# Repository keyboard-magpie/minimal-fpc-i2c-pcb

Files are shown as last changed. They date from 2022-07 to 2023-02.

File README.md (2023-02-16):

# minimal-fpc-i2c-pcb
Minimal adapter board for converting keyboard i2c oled pins to ffc/fpc ribbon cable for keyboards such as crkbd, kimiko or kyria, intended to make using cirque glidepoint trackpads easier with keyboards that already have an OLED header.
Screenshot_2022-07-07_at_13 14 48

# how to use
To use the TM035035 and TM040040 with 5v controllers, on the back trackpad, remove R1 for I2C, and remove R7 and R8 for 5V (leave these if using with 3v3 controllers i.e. rp2040.

# holders
In the holders folder you will find holders for the curved overlays (35 and 40mm- please note there was an earlier misnaming of these files which I have corrected as of 16 Feb 2023).

# production
Please note there is a small error in the cpl file for the ffc connector that comes from the footprint for it. JLC should correct its placement for you.

Connector used is this one from LCSC: https://lcsc.com/product-detail/FFC-FPC-Connectors_SHENZHEN-ATOM-TECH-FPC05012-09200_C479750.html

# alternative FPC connectors: 
https://www.digikey.co.uk/en/products/detail/hirose-electric-co-ltd/FH12-12S-0.5SH-55/1110374 \
https://www.digikey.co.uk/en/products/detail/gct/FFC2B35-12-G/15970866 \
Both of the above were suggested by u/idyllic on discord and look to have a footprint that is very close the the LCSC part above and should be compatible.

# ffc/fpc cables
Any generic flat flex cable can be used, they are 12 position, 0.5mm pitch, same-sided contacts. The molex extra flex and primo flex series from mouser seem to work well.

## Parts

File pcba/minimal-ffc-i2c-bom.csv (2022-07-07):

Comment | Designator | Footprint | LCSC Part #
4.7k Resistor | R1, R2 | Resistor_SMD:R_0805_2012Metric_Pad1.20x1.40mm_HandSolder | C441952
12 pin 0.5mm pitch FPC connector | J2 | minimal-ffc-i2c:FPC-SMD_FPC05012-09200-.5mm-rev | C479750

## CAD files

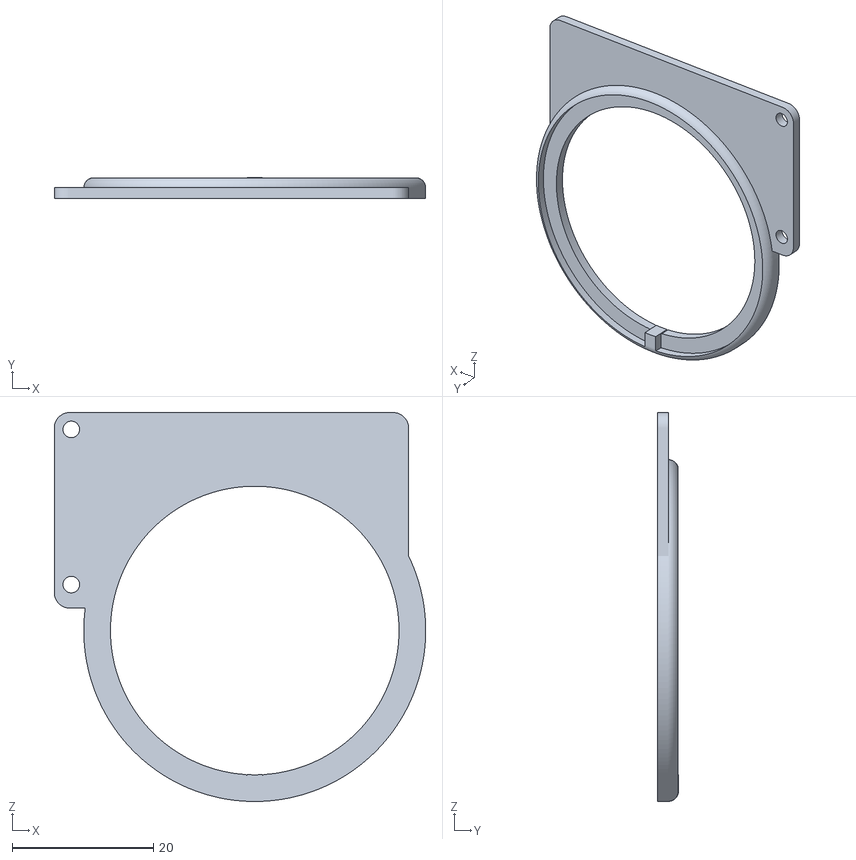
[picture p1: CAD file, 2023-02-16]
holders/lily-cirque40-curved-holder.stl
52.7 x 3.00 x 55.2

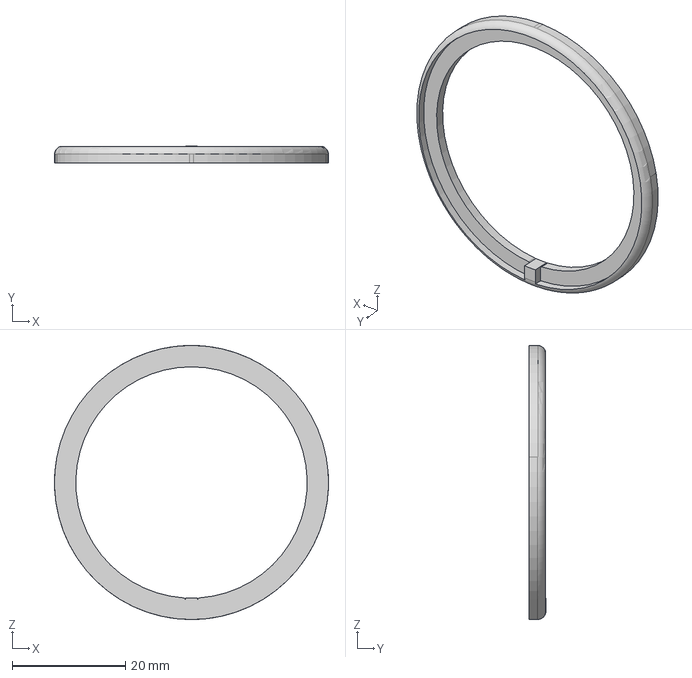
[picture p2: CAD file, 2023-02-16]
holders/cirque-40-curved-ring.step
48.5 x 3.00 x 48.5 mm

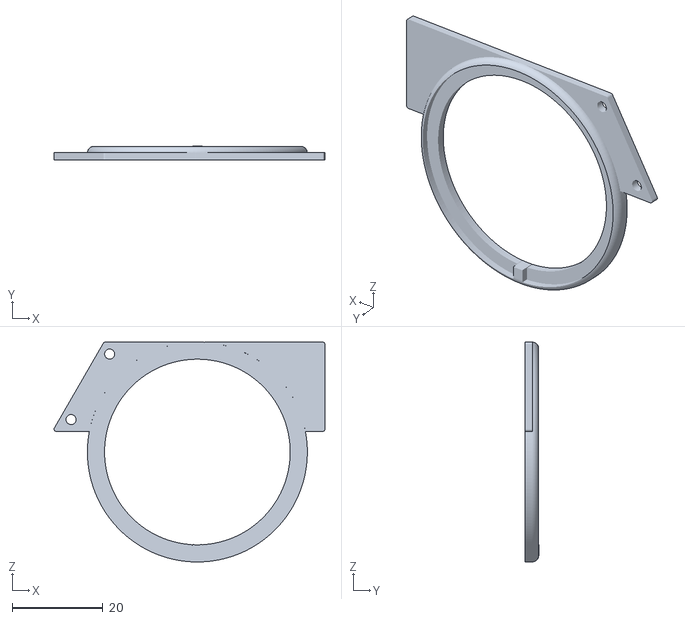
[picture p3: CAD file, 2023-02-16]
holders/crkbd-cirque40-curved-holder.stl
59.8 x 3.00 x 48.5

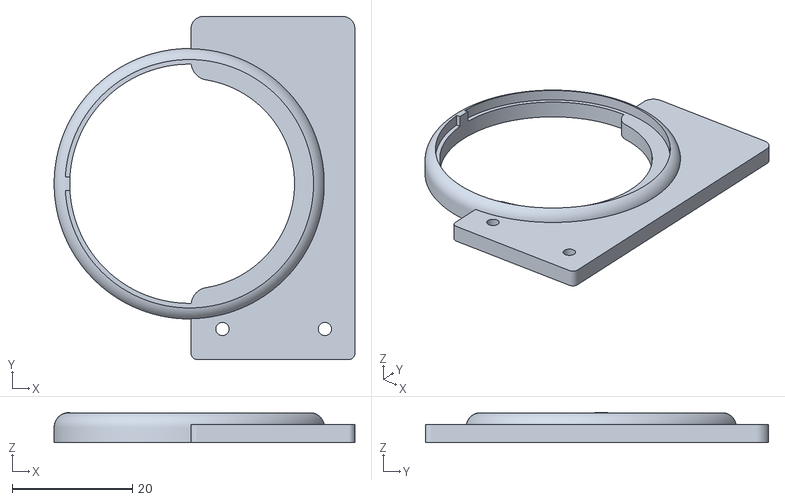
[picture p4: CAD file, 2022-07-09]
holders/kimiko-cirque35-holder v1.stl
50.0 x 57.1 x 5.00

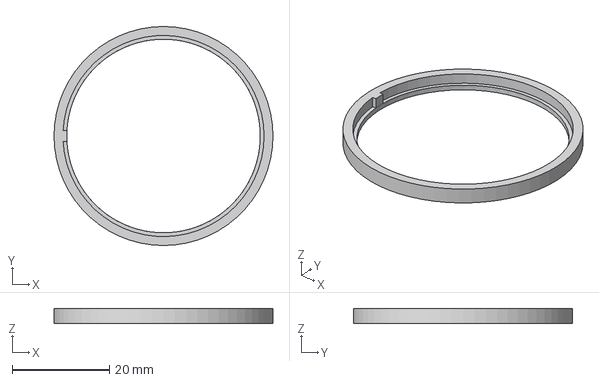
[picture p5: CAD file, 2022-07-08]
holders/cirque-35-curved-ring.step
45.0 x 45.0 x 3.00 mm

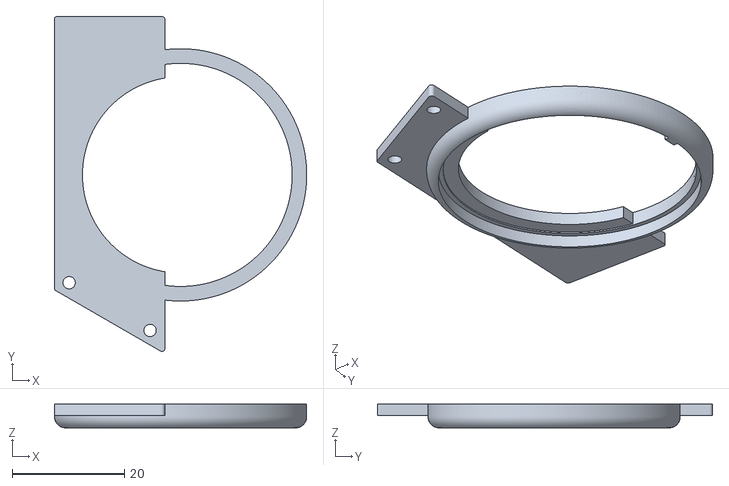
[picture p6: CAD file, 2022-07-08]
holders/corne-cirque35-holder v1.stl
45.0 x 59.8 x 4.25

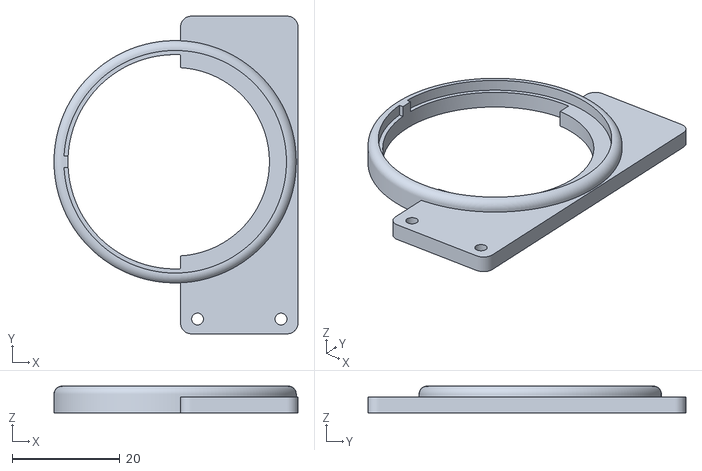
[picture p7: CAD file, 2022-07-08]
holders/sofle-cirque35-holder v1.stl
45.3 x 59.0 x 5.00

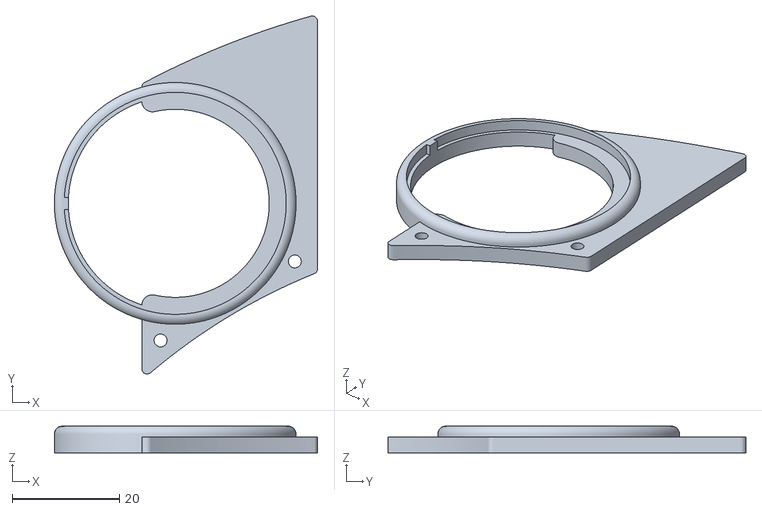
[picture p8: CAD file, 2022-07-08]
holders/kyria-cirque35-holder v1.stl
49.0 x 66.7 x 5.00

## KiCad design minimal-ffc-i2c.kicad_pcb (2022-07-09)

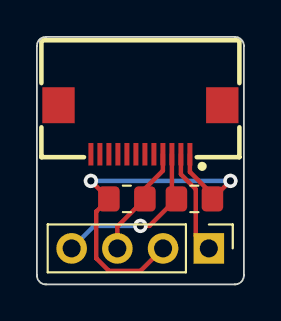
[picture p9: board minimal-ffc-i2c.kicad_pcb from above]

Board: 2 copper layers, 11.5 x 13.8 mm, 4 parts (0 on the bottom side), 4 nets.

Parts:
J1: Conn_01x04_Female; PinHeader_1x04_P2.54mm_Vertical
J2: Conn_01x12_Female; FPC-SMD_FPC05012-09200-.5mm-rev
R1, R2: 4k7; R_0805_2012Metric_Pad1.20x1.40mm_HandSolder

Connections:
gnd: J1.1, J2.2
sck: J1.3, J2.4, R1.1
sda: J1.4, J2.3, R2.1
vcc: J1.2, J2.1, R1.2, R2.2

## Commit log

2022-07-07 add pcba files
    [minimal-ffc-i2c-bom.csv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]
2022-07-08 add holder stls
    Holders for the 40mm cirques I've designed
    [corne-cirque40-holder v1.stl, kyria-cirque40-holder v1.stl, sofle-cirque40-holder v1.stl]
2022-07-08 Create cirque40ring v1.step
    [cirque40ring v1.step]
2022-07-09 vcc fix
    [minimal-ffc-i2c-B_Cu.gbr, minimal-ffc-i2c-B_Mask.gbr, minimal-ffc-i2c-B_Paste.gbr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]
2022-07-09 add kimiko holder
    [kimiko-cirque40-holder v1.stl]
2022-07-09 yes. something changed.
    [minimal-ffc-i2c.kicad_pcb]
2023-02-16 fix holder naming errors, update readme, add missing 40mm files
    [cirque-35-curved-ring.step, cirque-40-curved-ring.step, corne-cirque35-holder v1.stl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]
